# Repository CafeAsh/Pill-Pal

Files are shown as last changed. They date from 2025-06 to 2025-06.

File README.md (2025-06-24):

# Pill Pal Project
**Members:**  Ashton S, Damien W, Andrew J, Katherine S

## What is Pill Pal?

Pill Pal is a pill dispensing device developed by Team Fire through the course of UCLA's 2025 ECE 180DA/DW Capstone course.

Medication nonadherence poses serious risks, including hospitalization and mortality. Managing multiple medications demands strict adherence to schedules, accurate dosage measurement, and proper pill identification. In the United States alone, 43% of adults aged 65 and older take five or more prescription drugs.

Pill Pal simplifies medication management by offering an intuitive device for scheduling and dispensing pills. Unlike existing solutions like Hero Health and Meda Cube, Pill Pal stands out with advanced verification capabilities. It employs computer vision to not only count pills but also accurately identify them, reducing errors caused by both device and user.

## Scope of Project

* Aimed at individuals aged 65 and older, as well as their caregivers. 
* Accommodates pills ranging from 5mm to 21mm in size. 
* Compact design fits within maximum dimensions of 24in x 24in x 18in.
* Primary focus on pill verification subsystem.
* Outsourced pill retrieval method; no development efforts in this area.
* Targeting a verification error rate of less than 0.5%.

## Whats Involved
### Hardware
* Raspberry Pi 4B + 32GB Micro SD
* Raspberry Pi Camera Module V2
* Raspberry Pi 5" Touchscreen Display
* 2x MG90 Servos
* Difused White LED
### Computer Vision
* Ultralytics YoloV5n
* Custom Dataset
### User Interface
* Kivy Based Framework
### Housing
* Mixture of Standard and Matte PLA,

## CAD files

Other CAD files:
CAD_Files/Verification Blocks v20.f3z

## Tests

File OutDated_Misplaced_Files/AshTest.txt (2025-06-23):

Test: 1, Characteristics: {'oblong', 'pill', 'large', 'beige'}, Pill: ['MultiVitamin']
Test: 2, Characteristics: {'oblong', 'pill', 'large', 'beige'}, Pill: ['MultiVitamin']
Failed Test: 1, Characteristics: {'pill', 'oblong'}, Pill: []
Failed Test: 2, Characteristics: {'medium'}, Pill: []
Passed Test 1, Characteristics: {'oblong', 'beige'}, Pill: ['MultiVitamin']
Passed Test 2, Characteristics: {'oblong', 'beige'}, Pill: ['MultiVitamin']
Passed Test 3, Characteristics: {'oblong', 'beige'}, Pill: ['MultiVitamin']
Passed Test 4, Characteristics: {'oblong', 'beige'}, Pill: ['MultiVitamin']
Passed Test 5, Characteristics: {'oblong', 'beige'}, Pill: ['MultiVitamin']
Passed Test 6, Characteristics: {'oblong', 'beige'}, Pill: ['MultiVitamin']
Failed Test 1, Characteristics: {'oblong', 'pill'}, Pill: []
Failed Test 2, Characteristics: {'pill', 'large'}, Pill: []
Passed Test 3, Characteristics: {'oblong', 'white', 'small'}, Pill: ['Allertec']
Passed Test 4, Characteristics: {'medium', 'white'}, Pill: ['Zinc']
Failed Test 5, Characteristics: {'pill'}, Pill: []
Test Batch: 2025-05-14 21:56:29.531375Passed Test 1, Characteristics: {'medium', 'red', 'pill', 'blue'}, Pill: ['Tylenol']
Passed Test 2, Characteristics: {'large', 'oblong', 'beige'}, Pill: ['MultiVitamin']
Failed Test 3, Characteristics: {'pill'}, Pill: []
Test Batch: 2025-05-14 22:03:43.866070Test Batch: 2025-05-14 22:05:19.351595Failed Test 1, Characteristics: {'pill'}, Pill: []
Failed Test 2, Characteristics: {'pill', 'capsule', 'white'}, Pill: []
Failed Test 3, Characteristics: {'pill', 'white'}, Pill: []
Failed Test 4, Characteristics: {'capsule', 'pill'}, Pill: []
Failed Test 5, Characteristics: {'pill'}, Pill: []
Failed Test 6, Characteristics: {'pill'}, Pill: []

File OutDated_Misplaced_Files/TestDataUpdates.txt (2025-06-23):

Test: 1, Confidence: 0.8663991093635559
Test: 2, Confidence: 0.8826671838760376
Test: 3, Confidence: 0.8755373954772949
Test: 4, Confidence: 0.8511570692062378
Test: 5, Confidence: 0.8647085428237915
Test: 6, Confidence: 0.8529770970344543
Test: 7, Confidence: 0.8642621636390686
Test: 8, Confidence: 0.8169513940811157
Test: 9, Confidence: 0.8401616215705872
Test: 10, Confidence: 0.8167058825492859
Test: 11, Confidence: 0.753711462020874
Test: 12, Confidence: 0.8434830904006958
Test: 13, Confidence: 0.8218642473220825
Test: 14, Confidence: 0.8264126181602478
Test: 15, Confidence: 0.8553087115287781
Test: 16, Confidence: 0.7893893718719482
Test: 17, Confidence: 0.8077926635742188
Test: 18, Confidence: 0.8879213333129883
Test: 19, Confidence: 0.8521213531494141
Test: 20, Confidence: 0.8283798694610596
Test: 21, Confidence: 0.8602449297904968
Test: 22, Confidence: 0.64755779504776
Test: 23, Confidence: 0.8162557482719421
Test: 24, Confidence: 0.8518110513687134
Test: 25, Confidence: 0.8540529608726501
Test: 26, Confidence: 0.8430642485618591
Test: 27, Confidence: 0.8432045578956604
Test: 28, Confidence: 0.8785762190818787
Test: 29, Confidence: 0.8303031325340271
Test: 30, Confidence: 0.7792167067527771
Test: 31, Confidence: 0.8792150020599365
Test: 32, Confidence: 0.8754306435585022
Test: 33, Confidence: 0.8369922041893005
Test: 34, Confidence: 0.8724876642227173
Test: 35, Confidence: 0.7125908136367798
Test: 36, Confidence: 0.8801412582397461
Test: 37, Confidence: 0.8527312278747559
Test: 38, Confidence: 0.8252891898155212
Test: 39, Confidence: 0.8519672155380249
Test: 40, Confidence: 0.8726422786712646
Test: 41, Confidence: 0.6001267433166504
Test: 42, Confidence: 0.8835003972053528
Test: 43, Confidence: 0.8318778872489929
Test: 44, Confidence: 0.754368245601654
Test: 45, Confidence: 0.7924609780311584
Test: 46, Confidence: 0.8563061952590942
Test: 47, Confidence: 0.8038321733474731
Test: 48, Confidence: 0.8085771799087524
Test: 49, Confidence: 0.8533533215522766
Test: 50, Confidence: 0.8119551539421082
Test: 51, Confidence: 0.8488428592681885
Test: 52, Confidence: 0.8649629950523376
Test: 53, Confidence: 0.8574305772781372
Test: 54, Confidence: 0.8744310140609741
Test: 55, Confidence: 0.8364936709403992
Test: 56, Confidence: 0.8491111993789673
Test: 57, Confidence: 0.8860889673233032
Test: 58, Confidence: 0.824094831943512
Test: 59, Confidence: 0.8591299653053284
Test: 60, Confidence: 0.816805362701416
Test: 61, Confidence: 0.8369536995887756
Test: 62, Confidence: 0.8607133626937866
Test: 63, Confidence: 0.8628970384597778
Test: 64, Confidence: 0.7004595994949341
Test: 65, Confidence: 0.8639209866523743
Test: 66, Confidence: 0.83849036693573
Test: 67, Confidence: 0.8416141867637634
Test: 68, Confidence: 0.8494589328765869
Test: 69, Confidence: 0.8329309225082397
Test: 70, Confidence: 0.8591966032981873
Test: 71, Confidence: 0.8725012540817261
Test: 72, Confidence: 0.882864773273468
Test: 73, Confidence: 0.8827550411224365
Test: 74, Confidence: 0.8592625260353088
Test: 75, Confidence: 0.8543862104415894
Test: 76, Confidence: 0.8689223527908325
Test: 77, Confidence: 0.8844353556632996
Test: 78, Confidence: 0.8342261910438538
Test: 79, Confidence: 0.8248381018638611
Test: 80, Confidence: 0.8121533393859863
Test: 81, Confidence: 0.8526245355606079
Test: 82, Confidence: 0.8169139623641968
Test: 83, Confidence: 0.8201515674591064
Test: 84, Confidence: 0.8597942590713501
Test: 85, Confidence: 0.8630779385566711
Test: 86, Confidence: 0.8622211813926697
Test: 87, Confidence: 0.8374679684638977
Test: 88, Confidence: 0.8491995930671692
Test: 89, Confidence: 0.8860586881637573
Test: 90, Confidence: 0.8696560859680176
Test: 91, Confidence: 0.8290908336639404
Test: 92, Confidence: 0.8412095308303833
Test: 93, Confidence: 0.6310178637504578
Test: 94, Confidence: 0.880522608757019
Test: 95, Confidence: 0.8199472427368164
Test: 96, Confidence: 0.8109217286109924
Test: 97, Confidence: 0.8338972330093384
Test: 98, Confidence: 0.8236708641052246
Test: 99, Confidence: 0.6796160936355591
Test: 100, Confidence: 0.7799317836761475
Test: 9, Confidence: 0.8748241066932678
Test: 10, Confidence: 0.8788591027259827
Test: 11, Confidence: 0.8316600918769836
Test: 12, Confidence: 0.7983502149581909
Test: 13, Confidence: 0.815441906452179
Test: 14, Confidence: 0.7403838634490967
Test: 15, Confidence: 0.6905316114425659
Test: 16, Confidence: 0.8261948823928833
Test: 17, Confidence: 0.8175153732299805
Test: 18, Confidence: 0.8088531494140625
Test: 19, Confidence: 0.8539157509803772
Test: 20, Confidence: 0.7268420457839966
Test: 21, Confidence: 0.8576212525367737
Test: 22, Confidence: 0.8497840166091919
Test: 23, Confidence: 0.8285691142082214
Test: 24, Confidence: 0.874667763710022
Test: 25, Confidence: 0.8807705640792847
Test: 26, Confidence: 0.8769426941871643
Test: 27, Confidence: 0.8925943374633789
Test: 28, Confidence: 0.775532066822052
Test: 29, Confidence: 0.8142493367195129
Test: 30, Confidence: 0.7598199248313904
Test: 31, Confidence: 0.8821894526481628
Test: 32, Confidence: 0.7486389875411987
Test: 33, Confidence: 0.8874029517173767
Test: 34, Confidence: 0.8687301278114319
Test: 35, Confidence: 0.8379375338554382
Test: 36, Confidence: 0.8491209745407104
Test: 37, Confidence: 0.7861077189445496
Test: 38, Confidence: 0.8826022744178772
Test: 39, Confidence: 0.8248276114463806
Test: 40, Confidence: 0.8738111257553101
Test: 41, Confidence: 0.8320329785346985
Test: 42, Confidence: 0.6807191967964172
Test: 43, Confidence: 0.8621594309806824
Test: 44, Confidence: 0.8801345229148865
Test: 45, Confidence: 0.8657287955284119
Test: 46, Confidence: 0.6759946346282959
Test: 47, Confidence: 0.8897563219070435
Test: 48, Confidence: 0.8624711036682129
Test: 49, Confidence: 0.8487997055053711
Test: 50, Confidence: 0.5480730533599854
Test: 51, Confidence: 0.8382814526557922
Test: 52, Confidence: 0.8456729650497437
Test: 53, Confidence: 0.6184303164482117
Test: 54, Confidence: 0.8347060680389404
Test: 55, Confidence: 0.8688293099403381
Test: 1, Confidence: 0.8461774587631226
Test: 2, Confidence: 0.781511664390564
Test: 3, Confidence: 0.8389360308647156
Test: 4, Confidence: 0.8615061044692993
Test: 5, Confidence: 0.8335949182510376
Test: 6, Confidence: 0.7853469252586365
Test: 7, Confidence: 0.8862441778182983
Test: 8, Confidence: 0.7606112957000732
Test: 9, Confidence: 0.8670732975006104
Test: 10, Confidence: 0.8553711771965027
Test: 11, Confidence: 0.8486812114715576
Test: 12, Confidence: 0.8651771545410156
Test: 13, Confidence: 0.8754342794418335
Test: 14, Confidence: 0.8251563310623169
Test: 15, Confidence: 0.7951398491859436
Test: 16, Confidence: 0.8622942566871643
Test: 17, Confidence: 0.8205395340919495

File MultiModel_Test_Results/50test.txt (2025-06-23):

Test: 1, Characteristics: {'capsule', 'blue', 'red', 'medium'}, Pill: ['Tylenol']
Test: 2, Characteristics: {'capsule', 'red', 'medium', 'blue'}, Pill: ['Tylenol']
Test: 3, Characteristics: {'capsule', 'red', 'medium', 'blue'}, Pill: ['Tylenol']
Test: 4, Characteristics: {'capsule', 'blue', 'red', 'medium'}, Pill: ['Tylenol']
Test: 5, Characteristics: {'capsule', 'red', 'medium', 'blue'}, Pill: ['Tylenol']
Test: 1, Characteristics: {'blue', 'red', 'capsule', 'medium'}, Pill: ['Tylenol']
Test: 2, Characteristics: {'blue', 'red', 'capsule', 'medium'}, Pill: ['Tylenol']
Test: 3, Characteristics: {'blue', 'red', 'capsule'}, Pill: ['Tylenol']
Test: 4, Characteristics: {'blue', 'red', 'capsule', 'medium'}, Pill: ['Tylenol']
Test: 5, Characteristics: {'blue', 'red', 'medium'}, Pill: ['Tylenol']
Test: 6, Characteristics: {'blue', 'red', 'capsule', 'medium'}, Pill: ['Tylenol']
Test: 7, Characteristics: {'blue', 'red'}, Pill: ['Tylenol']
Test: 8, Characteristics: {'blue', 'red', 'capsule'}, Pill: ['Tylenol']
Test: 9, Characteristics: {'blue', 'red', 'capsule', 'medium'}, Pill: ['Tylenol']
Test: 10, Characteristics: {'blue', 'red', 'capsule', 'medium'}, Pill: ['Tylenol']
Test: 11, Characteristics: {'blue', 'red', 'capsule', 'medium'}, Pill: ['Tylenol']
Test: 12, Characteristics: {'blue', 'red', 'capsule', 'medium'}, Pill: ['Tylenol']
Test: 13, Characteristics: {'blue', 'red', 'capsule', 'medium'}, Pill: ['Tylenol']
Test: 14, Characteristics: {'blue', 'red', 'capsule', 'medium'}, Pill: ['Tylenol']
Test: 15, Characteristics: {'blue', 'red', 'capsule', 'medium'}, Pill: ['Tylenol']
Test: 16, Characteristics: {'blue', 'red', 'capsule', 'medium'}, Pill: ['Tylenol']
Test: 17, Characteristics: {'blue', 'red', 'capsule'}, Pill: ['Tylenol']

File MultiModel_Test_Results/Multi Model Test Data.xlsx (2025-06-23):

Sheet: Aleve
Test # | Fail/Pass | Color | Shape | Size | Pill
1 | Pass | Blue | Oblong | Medium | Aleve
2 | Fail | NA | NA | NA | NA
3 | Pass | Blue | Oblong | Medium | Aleve
4 | Fail | NA | NA | Medium | NA
5 | Pass | Blue | Oblong | Medium | Aleve
6 | Fail | NA | NA | Medium | NA
7 | Pass | Blue | Oblong | Medium | Aleve
8 | Pass | Blue | Oblong | Medium | Aleve
9 | Fail | NA | NA | Medium | NA
10 | Fail | NA | NA | Medium | NA
11 | Pass | Blue | NA | Medium | Aleve
12 | Pass | Blue | Oblong | NA | Aleve
13 | Fail | NA | NA | NA | NA
14 | Fail | NA | Oblong | Medium | NA
15 | Fail | NA | Oblong | Medium | NA
16 | Pass | Blue | Oblong | NA | Aleve
17 | Fail | NA | NA | NA | NA
18 | Pass | Blue | NA | Medium | Aleve
19 | Pass | Blue | Oblong | Medium | Aleve
20 | Fail | Blue | NA | Medium | NA
21 | Pass | Blue | Oblong | Medium | Aleve
22 | Pass | Blue | Oblong | NA | Aleve
23 | Fail | Blue | NA | NA | NA
24 | Fail | Blue | NA | Medium | NA
25 | Fail | Blue | NA | NA | NA
26 | Pass | Blue | NA | Medium | Aleve
27 | Pass | Blue | NA | Medium | Aleve
28 | Pass | Blue | Oblong | NA | Aleve
29 | Fail | NA | NA | NA | NA
30 | Pass | Blue | NA | Medium | Aleve
31 | Pass | Blue | Oblong | NA | Aleve
32 | Fail | NA | NA | Medium | NA
33 | Pass | Blue | Oblong | NA | Aleve
34 | Pass | Blue | Oblong | Medium | Aleve
35 | Fail | Blue | NA | NA | NA
36 | Pass | Blue | NA | Medium | Aleve
37 | Pass | Blue | NA | Medium | Aleve
38 | Fail | NA | NA | NA | NA
39 | Fail | NA | NA | Medium | NA
40 | Pass | Blue | Oblong | Medium | Aleve
41 | Pass | Blue | Oblong | NA | Aleve
42 | Pass | Blue | Oblong | Medium | Aleve
43 | Fail | Blue | NA | NA | NA
44 | Pass | Blue | Oblong | Medium | Aleve
45 | Pass | Blue | NA | Medium | Aleve
46 | Fail | Blue | NA | NA | NA
47 | Fail | Blue | Oblong | Medium | NA
48 | Fail | Blue | Oblong | NA | NA
49 | Fail | Blue | NA | Medium | NA
50 | Pass | Blue | Oblong | Medium | Aleve
51 | Pass | Blue | NA | Medium | Aleve

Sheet: Allertec
Test # | Fail/Pass | Color | Shape | Size | Pill
1 | Pass | White | Oblong | Small | Allertec
2 | Fail | NA | Oblong | Small | NA
3 | Fail | White | Oblong | NA | NA
4 | Fail | NA | Oblong | Small | NA
5 | Pass | White | Oblong | Small | Allertec
6 | Fail | NA | NA | NA | NA
7 | Fail | White | Oblong | Small | Allertec
8 | Fail | NA | Oblong | NA | NA
9 | Pass | White | Oblong | Small | Allertec
10 | Fail | White | Oblong | NA | NA
11 | Fail | NA | NA | NA | NA
12 | Fail | White | Oblong | NA | NA
13 | Fail | NA | Oblong | NA | NA
14 | Pass | Red | Disk | NA | Iron
15 | Pass | Red | NA | NA | Iron
16 | Pass | White | Oblong | Small | Allertec
17 | Fail | NA | Oblong | NA | NA
18 | Pass | White | Oblong | Small | Allertec
19 | Pass | White | Oblong | Small | Allertec
20 | Fail | NA | NA | NA | NA
21 | Pass | White | Oblong | Small | Allertec
22 | Fail | NA | Oblong | Small | NA
23 | Fail | NA | Oblong | NA | NA
24 | Pass | White | Oblong | Small | Allertec
25 | Fail | NA | Oblong | Small | NA
26 | Fail | NA | NA | NA | NA
27 | Pass | White | Oblong | Small | Allertec
28 | Fail | NA | Oblong | NA | NA
29 | Fail | NA | Oblong | NA | NA
30 | Pass | NA | NA | Medium | NA
31 | Pass | White | Oblong | Small | Allertec
32 | Fail | NA | Oblong | NA | NA
33 | Fail | NA | NA | NA | NA
34 | Fail | NA | NA | NA | NA
35 | Fail | NA | NA | NA | NA
36 | Pass | Red | Disk | NA | Iron
37 | Fail | White | Oblong | NA | NA
38 | Pass | White | Oblong | Small | Allertec
39 | Fail | NA | Oblong | NA | NA
40 | Fail | NA | NA | NA | NA
41 | Fail | NA | Oblong | NA | NA
42 | Fail | NA | NA | NA | NA
43 | Pass | White | Oblong | Small | Allertec
44 | Fail | White | Oblong | NA | NA
45 | Fail | NA | NA | NA | NA
46 | Fail | NA | Oblong | NA | NA
47 | Pass | White | Oblong | Small | Allertec
48 | Fail | White | Oblong | NA | NA
49 | Fail | NA | NA | NA | NA
50 | Fail | NA | NA | NA | NA
51 | Fail | NA | Oblong | NA | NA
52 | Fail | NA | NA | NA | NA
53 | Fail | NA | NA | NA | NA
54 | Fail | NA | NA | NA | NA

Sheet: Caffeine
Test # | Fail/Pass | Color | Shape | Size | Pill
1 | Fail | NA | Capsule | NA | NA
2 | Fail | NA | Capsule | NA | NA
3 | Fail | NA | NA | NA | NA
4 | Fail | NA | Capsule | NA | NA
5 | Fail | NA | NA | NA | NA
6 | Fail | NA | NA | NA | NA
7 | Fail | White | Capsule | NA | NA
8 | Fail | White | Capsule | NA | NA
9 | Fail | White | NA | NA | NA
10 | Fail | NA | Capsule | NA | NA
11 | Pass | White | Capsule | NA | Caffeine
12 | Fail | NA | NA | NA | NA
13 | Fail | NA | Capsule | NA | NA
14 | Fail | White | NA | NA | NA
15 | Fail | White | NA | NA | NA
16 | Fail | White | Capsule | NA | NA
17 | Fail | White | Capsule | NA | NA
18 | Fail | White | Capsule | NA | NA
19 | Fail | White | NA | NA | NA
20 | Fail | NA | NA | NA | NA
21 | Fail | White | NA | NA | NA
22 | Fail | NA | NA | NA | NA
23 | Fail | NA | Capsule | NA | NA
24 | Fail | NA | Capsule | NA | NA
25 | Fail | NA | Capsule | NA | NA
26 | Fail | White | NA | NA | NA
27 | Fail | White | NA | NA | NA
28 | Fail | NA | Capsule | NA | NA
29 | Fail | White | Capsule | NA | NA
30 | Fail | White | NA | NA | NA
31 | Fail | NA | Capsule | NA | NA
32 | Fail | White | NA | NA | NA
33 | Fail | NA | NA | NA | NA
34 | Fail | NA | Capsule | NA | NA
35 | Fail | NA | Capsule | NA | NA
36 | Fail | White | Capsule | NA | NA
37 | Fail | White | NA | NA | NA
38 | Fail | White | NA | NA | NA
39 | Fail | NA | Capsule | NA | NA
40 | Fail | White | NA | NA | NA
41 | Fail | White | NA | NA | NA
42 | Fail | NA | Capsule | NA | NA
43 | Fail | NA | Capsule | NA | NA
44 | Fail | NA | Capsule | NA | NA
45 | Fail | NA | NA | NA | NA
46 | Fail | NA | Capsule | NA | NA
47 | Fail | NA | NA | NA | NA
48 | Fail | NA | Capsule | NA | NA
49 | Fail | NA | Capsule | NA | NA
50 | Fail | White | Capsule | NA | NA

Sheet: Cordyceps
Test # | Fail/Pass | Color | Shape | Size | Pill
1 | Fail | NA | NA | Large | NA
2 | Fail | NA | NA | Large | NA
3 | Fail | NA | NA | Large | NA
4 | Fail | NA | NA | Large | NA
5 | Fail | NA | NA | Large | NA
6 | Fail | NA | NA | Large | NA
7 | Fail | NA | NA | Large | NA
8 | Fail | NA | NA | Large | NA
9 | Fail | NA | NA | Large | NA
10 | Fail | NA | NA | Large | NA
11 | Fail | NA | NA | Large | NA
12 | Fail | NA | NA | Large | NA
13 | Fail | NA | NA | Large | NA
14 | Fail | NA | NA | Large | NA
15 | Fail | NA | NA | Large | NA
16 | Fail | NA | NA | Large | NA
17 | Fail | NA | NA | Large | NA
18 | Fail | NA | NA | Large | NA
19 | Fail | NA | NA | Large | NA
20 | Fail | NA | NA | Large | NA
21 | Fail | NA | NA | Large | NA
22 | Fail | NA | NA | Large | NA
23 | Fail | NA | NA | Large | NA
24 | Fail | NA | NA | Large | NA
25 | Fail | NA | NA | Large | NA
26 | Fail | NA | NA | Large | NA
27 | Fail | NA | NA | Large | NA
28 | Fail | NA | NA | Large | NA
29 | Fail | NA | Capsule | Large | NA
30 | Fail | NA | NA | Large | NA
31 | Fail | NA | NA | Large | NA
32 | Fail | NA | NA | Large | NA
33 | Fail | NA | NA | Large | NA
34 | Fail | NA | NA | Large | NA
35 | Fail | NA | Capsule | Large | NA
36 | Fail | NA | NA | Large | NA
37 | Fail | Beige | NA | NA | NA
38 | Fail | NA | NA | Large | NA
39 | Fail | NA | NA | Large | NA
40 | Fail | NA | Capsule | Large | NA
41 | Fail | NA | NA | Large | NA
42 | Fail | Beige | NA | Large | NA
43 | Fail | NA | NA | Large | NA
44 | Fail | NA | NA | Large | NA
45 | Fail | NA | NA | Large | NA
46 | Fail | NA | NA | Large | NA
47 | Fail | NA | NA | Large | NA
48 | Fail | NA | NA | Large | NA
49 | Fail | NA | NA | Large | NA
50 | Fail | NA | Capsule | Large | NA

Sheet: Iron
Test # | Pass/Fail | Color | Shape | Size | Pill
1 | Pass | Red | Disk | Medium | Iron
2 | Pass | Red | Disk | Medium | Iron
3 | Fail | Red | NA | Medium | NA
4 | Pass | Red | Disk | Medium | Iron
5 | Fail | NA | NA | Medium | NA
6 | Pass | Red | Disk | Medium | Iron
7 | Pass | Red | Disk | Medium | Iron
8 | Fail | NA | Disk | Medium | NA
9 | Pass | Red | Disk | Medium | Iron
10 | Pass | Red | Disk | Medium | Iron
11 | Pass | Red | Disk | Medium | Iron
12 | Pass | Red | Disk | Medium | Iron
13 | Pass | Red | Disk | Medium | Iron
14 | Fail | NA | NA | Medium | NA
15 | Pass | Red | Disk | Medium | Iron
16 | Pass | Red | Disk | Medium | Iron
17 | Pass | Red | Disk | Medium | Iron
18 | Pass | Red | Disk | Medium | Iron
19 | Pass | Red | Disk | Medium | Iron
20 | Fail | NA | NA | Medium | NA
21 | Fail | NA | Disk | Medium | NA
22 | Pass | Red | Disk | Medium | Iron
23 | Fail | NA | Disk | Medium | NA
24 | Fail | Red | NA | Medium | NA
25 | Fail | NA | NA | Medium | NA
26 | Pass | Red | Disk | Medium | Iron
27 | Fail | Red | NA | Medium | NA
28 | Fail | NA | NA | Medium | NA
29 | Fail | Red | NA | Medium | NA
30 | Pass | Red | Disk | Medium | Iron
31 | Pass | Red | Disk | Medium | Iron
32 | Fail | Red | NA | Medium | NA
35 | Fail | Red | NA | Medium | NA
36 | Fail | NA | Disk | Medium | NA
37 | Fail | NA | NA | Medium | NA
38 | Pass | Red | Disk | Medium | Iron
39 | Pass | Red | Disk | Medium | Iron
40 | Pass | Red | Disk | Medium | Iron
41 | Pass | Red | Disk | Medium | Iron
42 | Pass | Red | Disk | Medium | Iron
43 | Pass | Red | Disk | Medium | Iron
44 | Pass | Red | Disk | Medium | Iron
45 | Fail | NA | NA | Medium | NA
46 | Pass | Red | Disk | Medium | Iron
47 | Fail | NA | NA | Medium | NA
48 | Pass | Red | Disk | Medium | Iron
49 | Fail | Red | NA | Medium | NA
50 | Fail | NA | NA | Medium | NA
51 | Fail | Red | NA | Medium | NA
52 | Pass | Red | Disk | Medium | Iron
53 | Pass | Red | Disk | Medium | Iron
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

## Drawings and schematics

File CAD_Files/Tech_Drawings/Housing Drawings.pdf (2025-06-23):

# 2.98in 4.52in

# 2.05in 1.94in Ø12.13in 2.3in

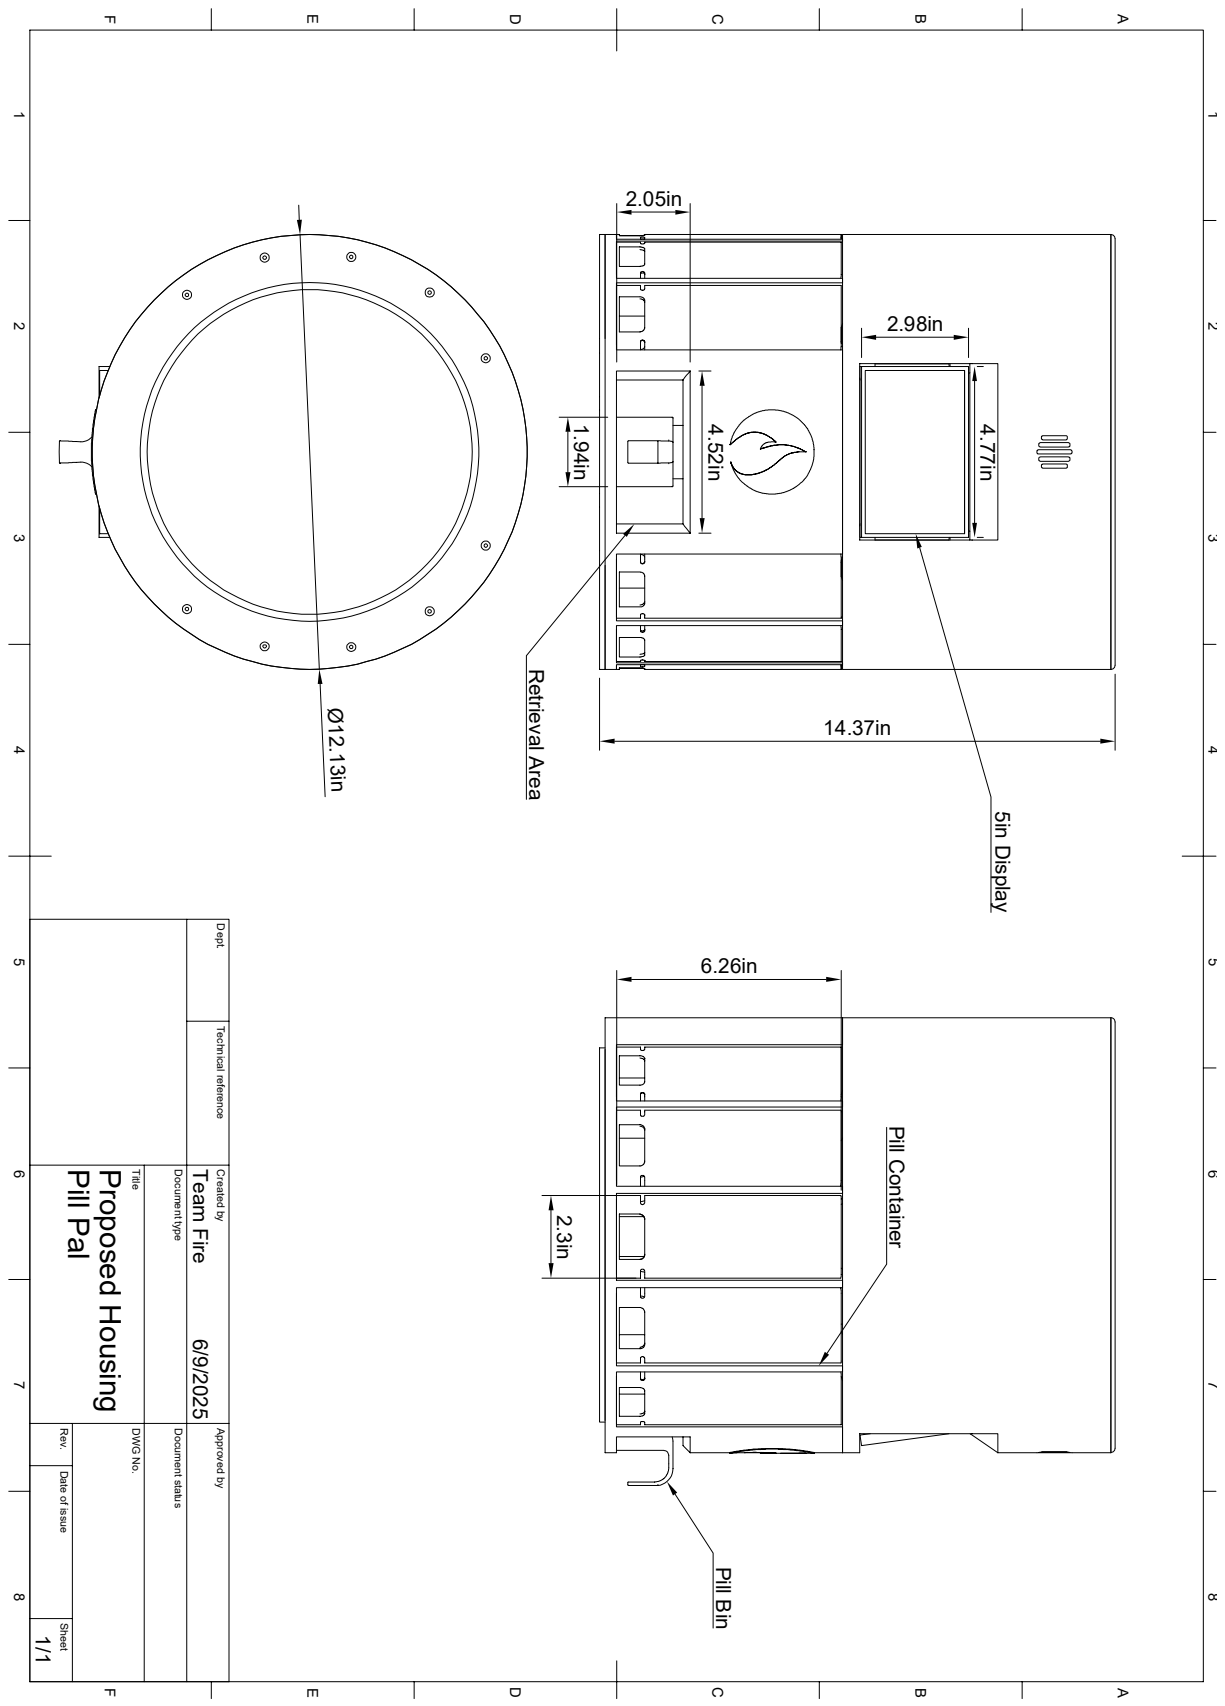
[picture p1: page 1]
5in Display Pill Container Pill Bin Retrieval Area

1 A 2 3 4 5 6 7 8 1 2 3 4 5 6 7 8 FEDCB FEDCBA Dept. Technical reference Created by Approved by Title DWG No. Document type Document status Rev. Date of issue Sheet 6/9/2025 1/1 Pill Pal Proposed Housing Team Fire

4.37in 2.36in 3.37in | .7in | 31 ° 5

.08in

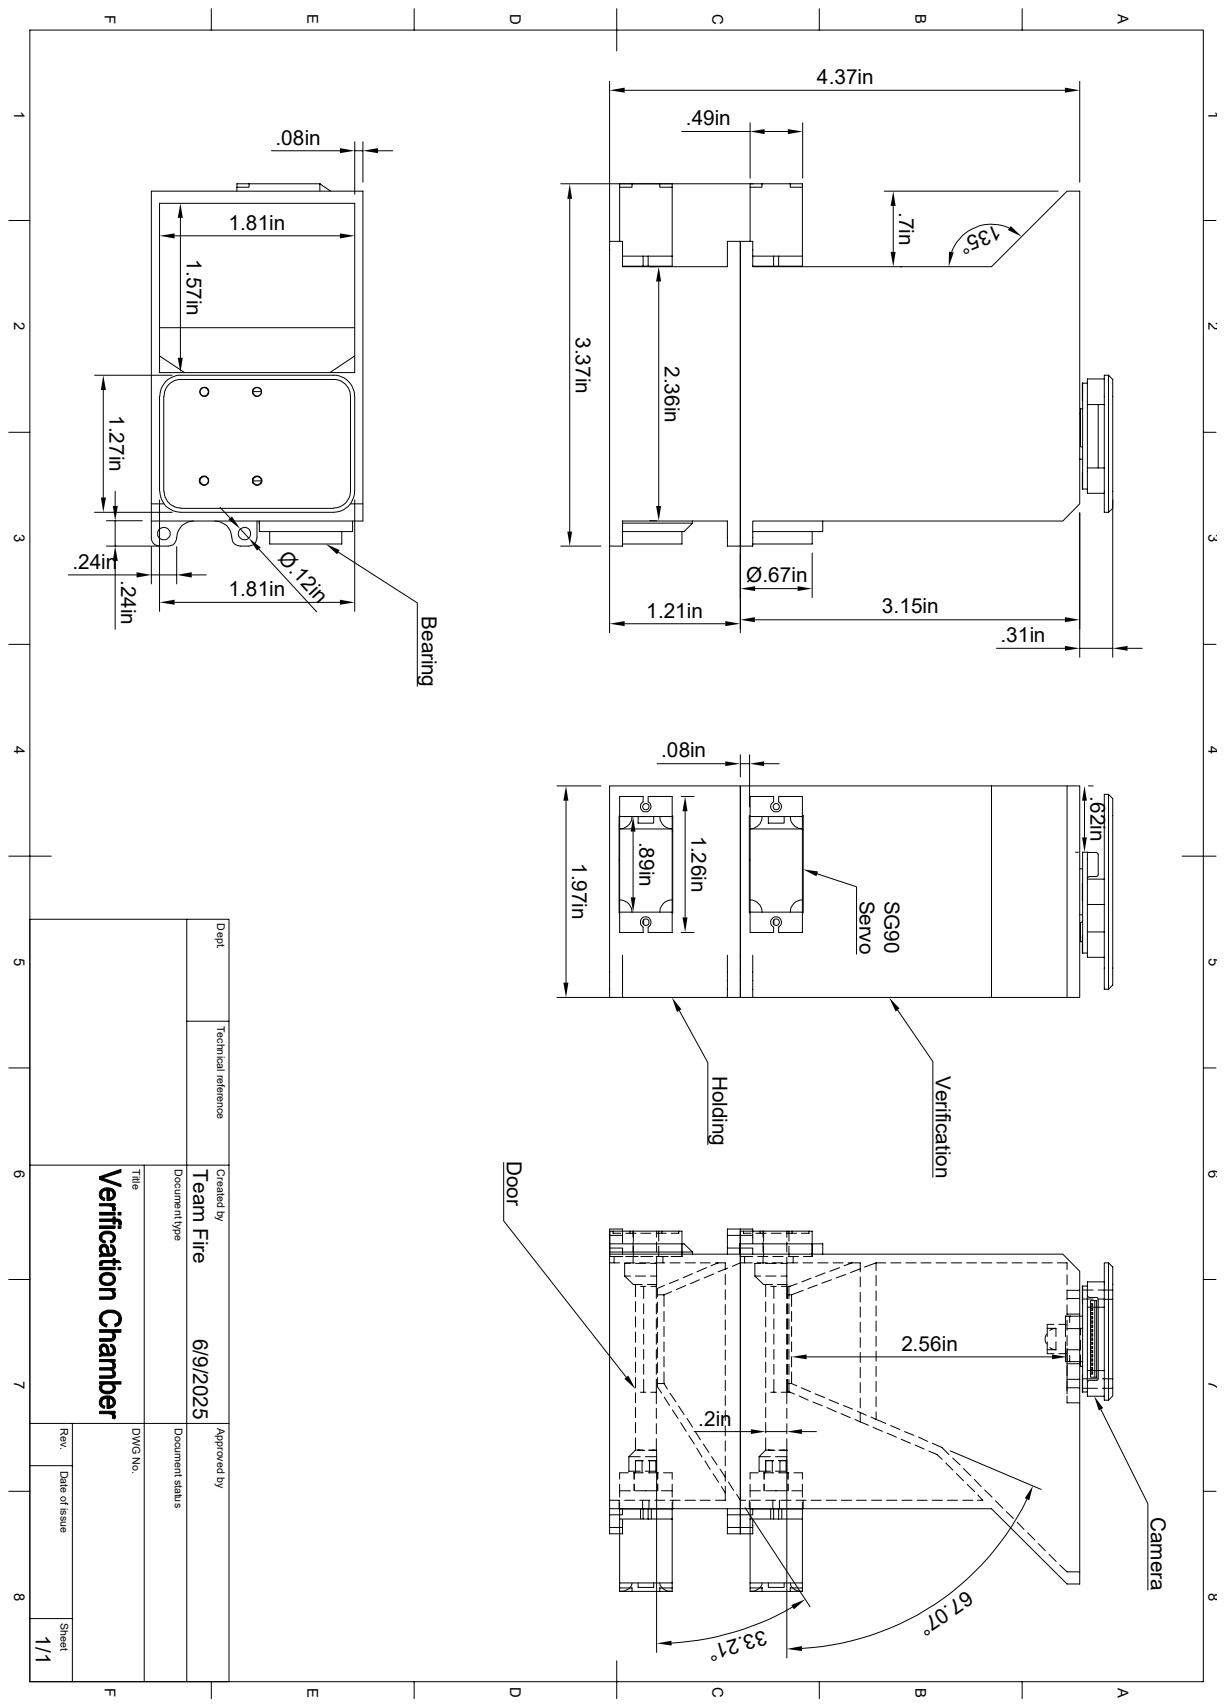
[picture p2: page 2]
2.56in 33 12. ° Holding; Verification; Camera Servo SG90 Bearing; Door

1 A 2 3 4 5 6 7 8 1 2 3 4 5 6 7 8 FEDCB FEDCBA Dept. Technical reference Created by Approved by Title DWG No. Document type Document status Rev. Date of issue Sheet 6/9/2025 1/1 Team Fire

6.26in

# .71in 1.27in

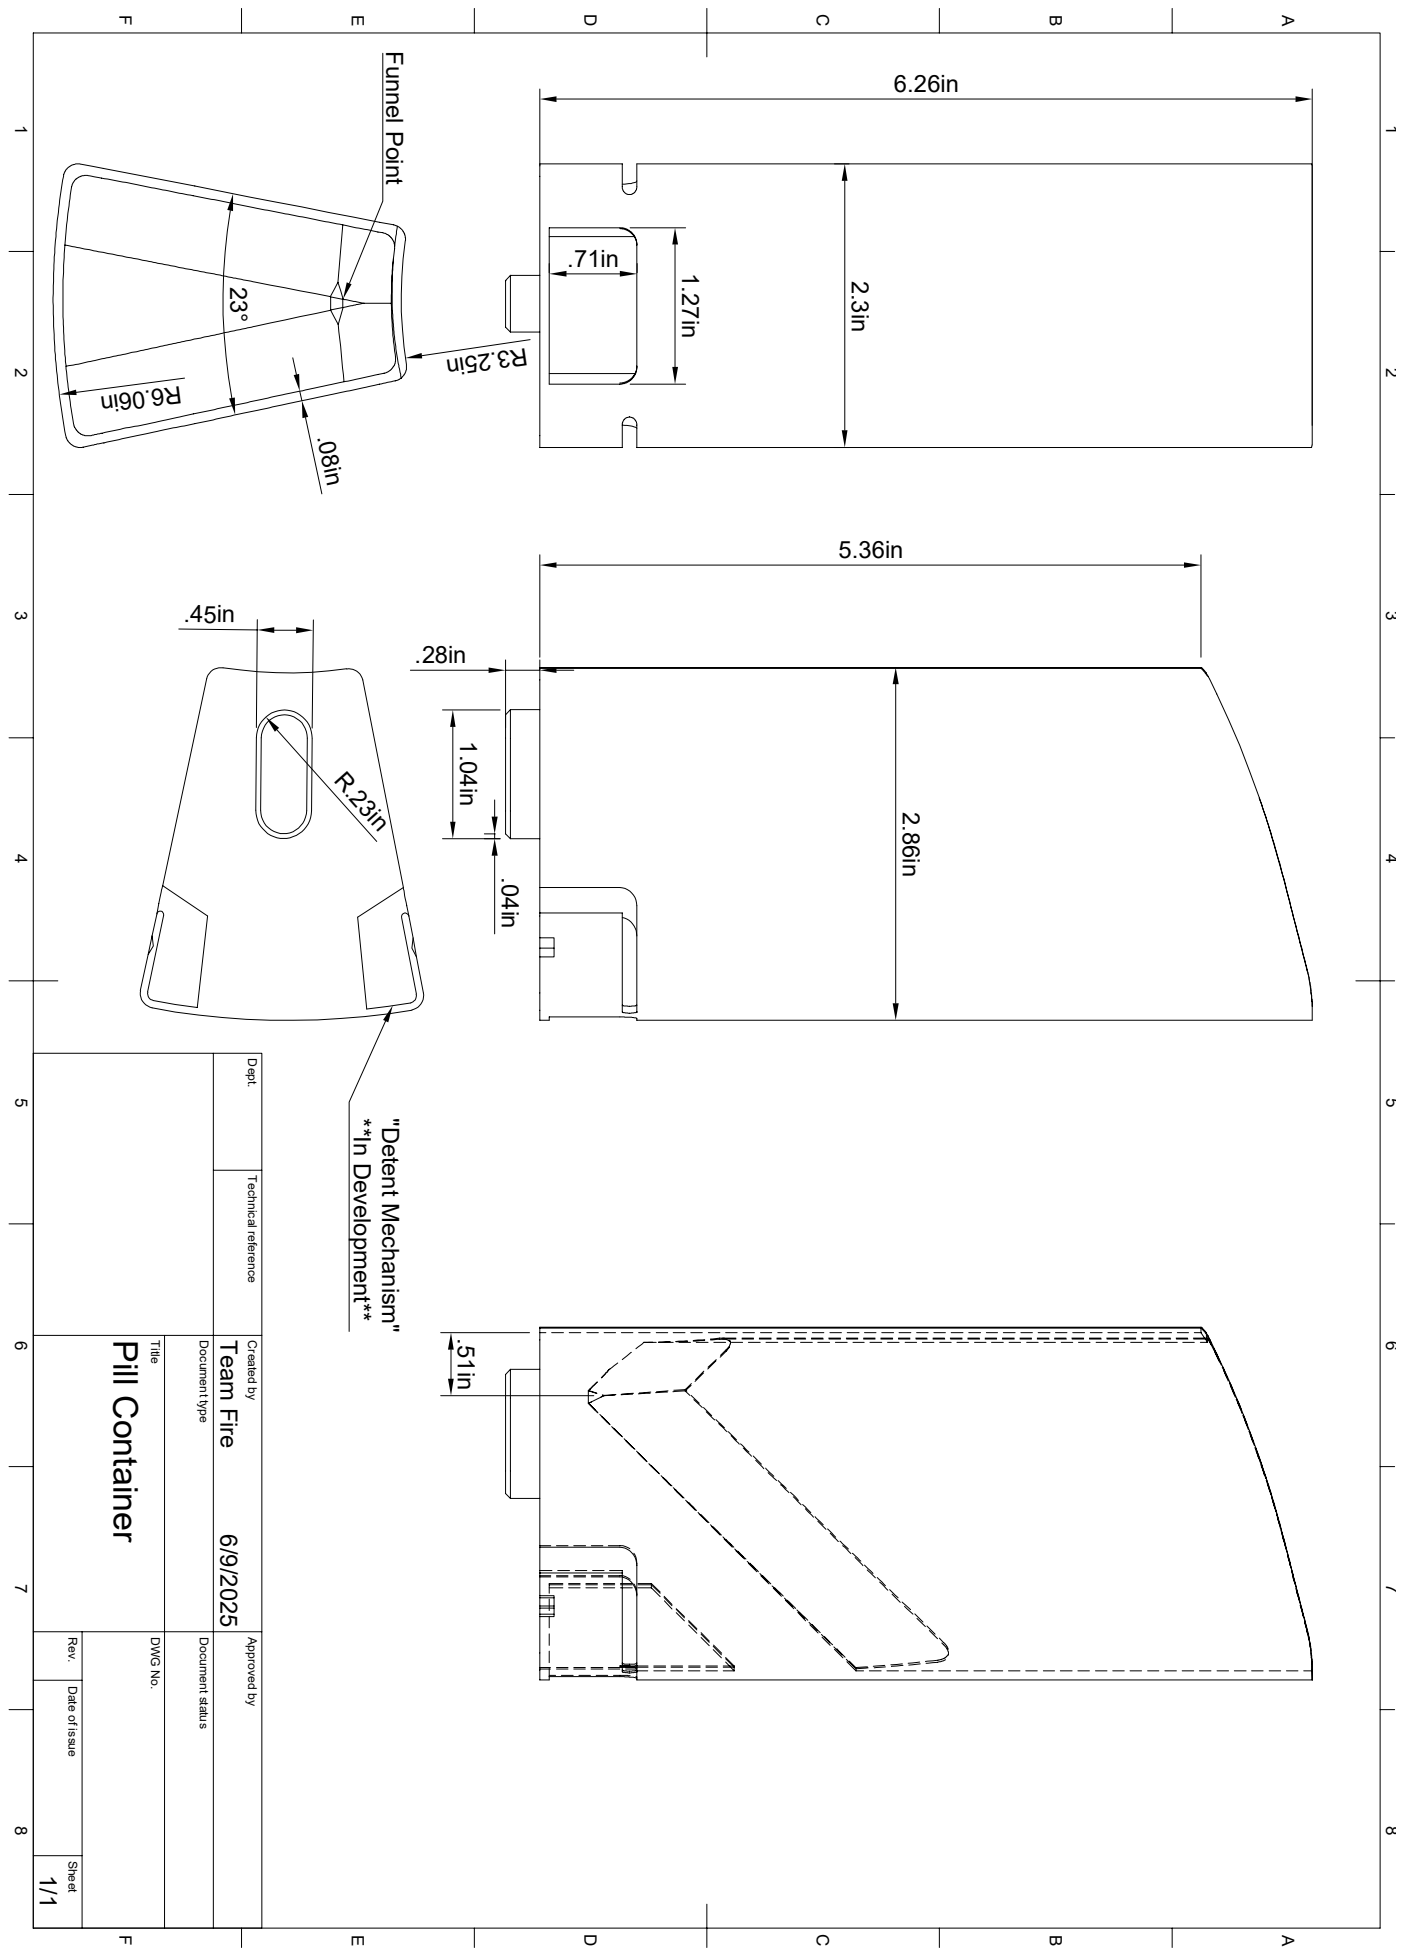
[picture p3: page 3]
2.86in Funnel Point **In Development** "Detent Mechanism"

1 A 2 3 4 5 6 7 8 1 2 3 4 5 6 7 8 FEDCB FEDCBA Dept. Technical reference Created by Approved by Title DWG No. Document type Document status Rev. Date of issue Sheet 6/9/2025 1/1 Pill Container Team Fire 52. 3 R ni i 60. 6 R n 23° 2.3in

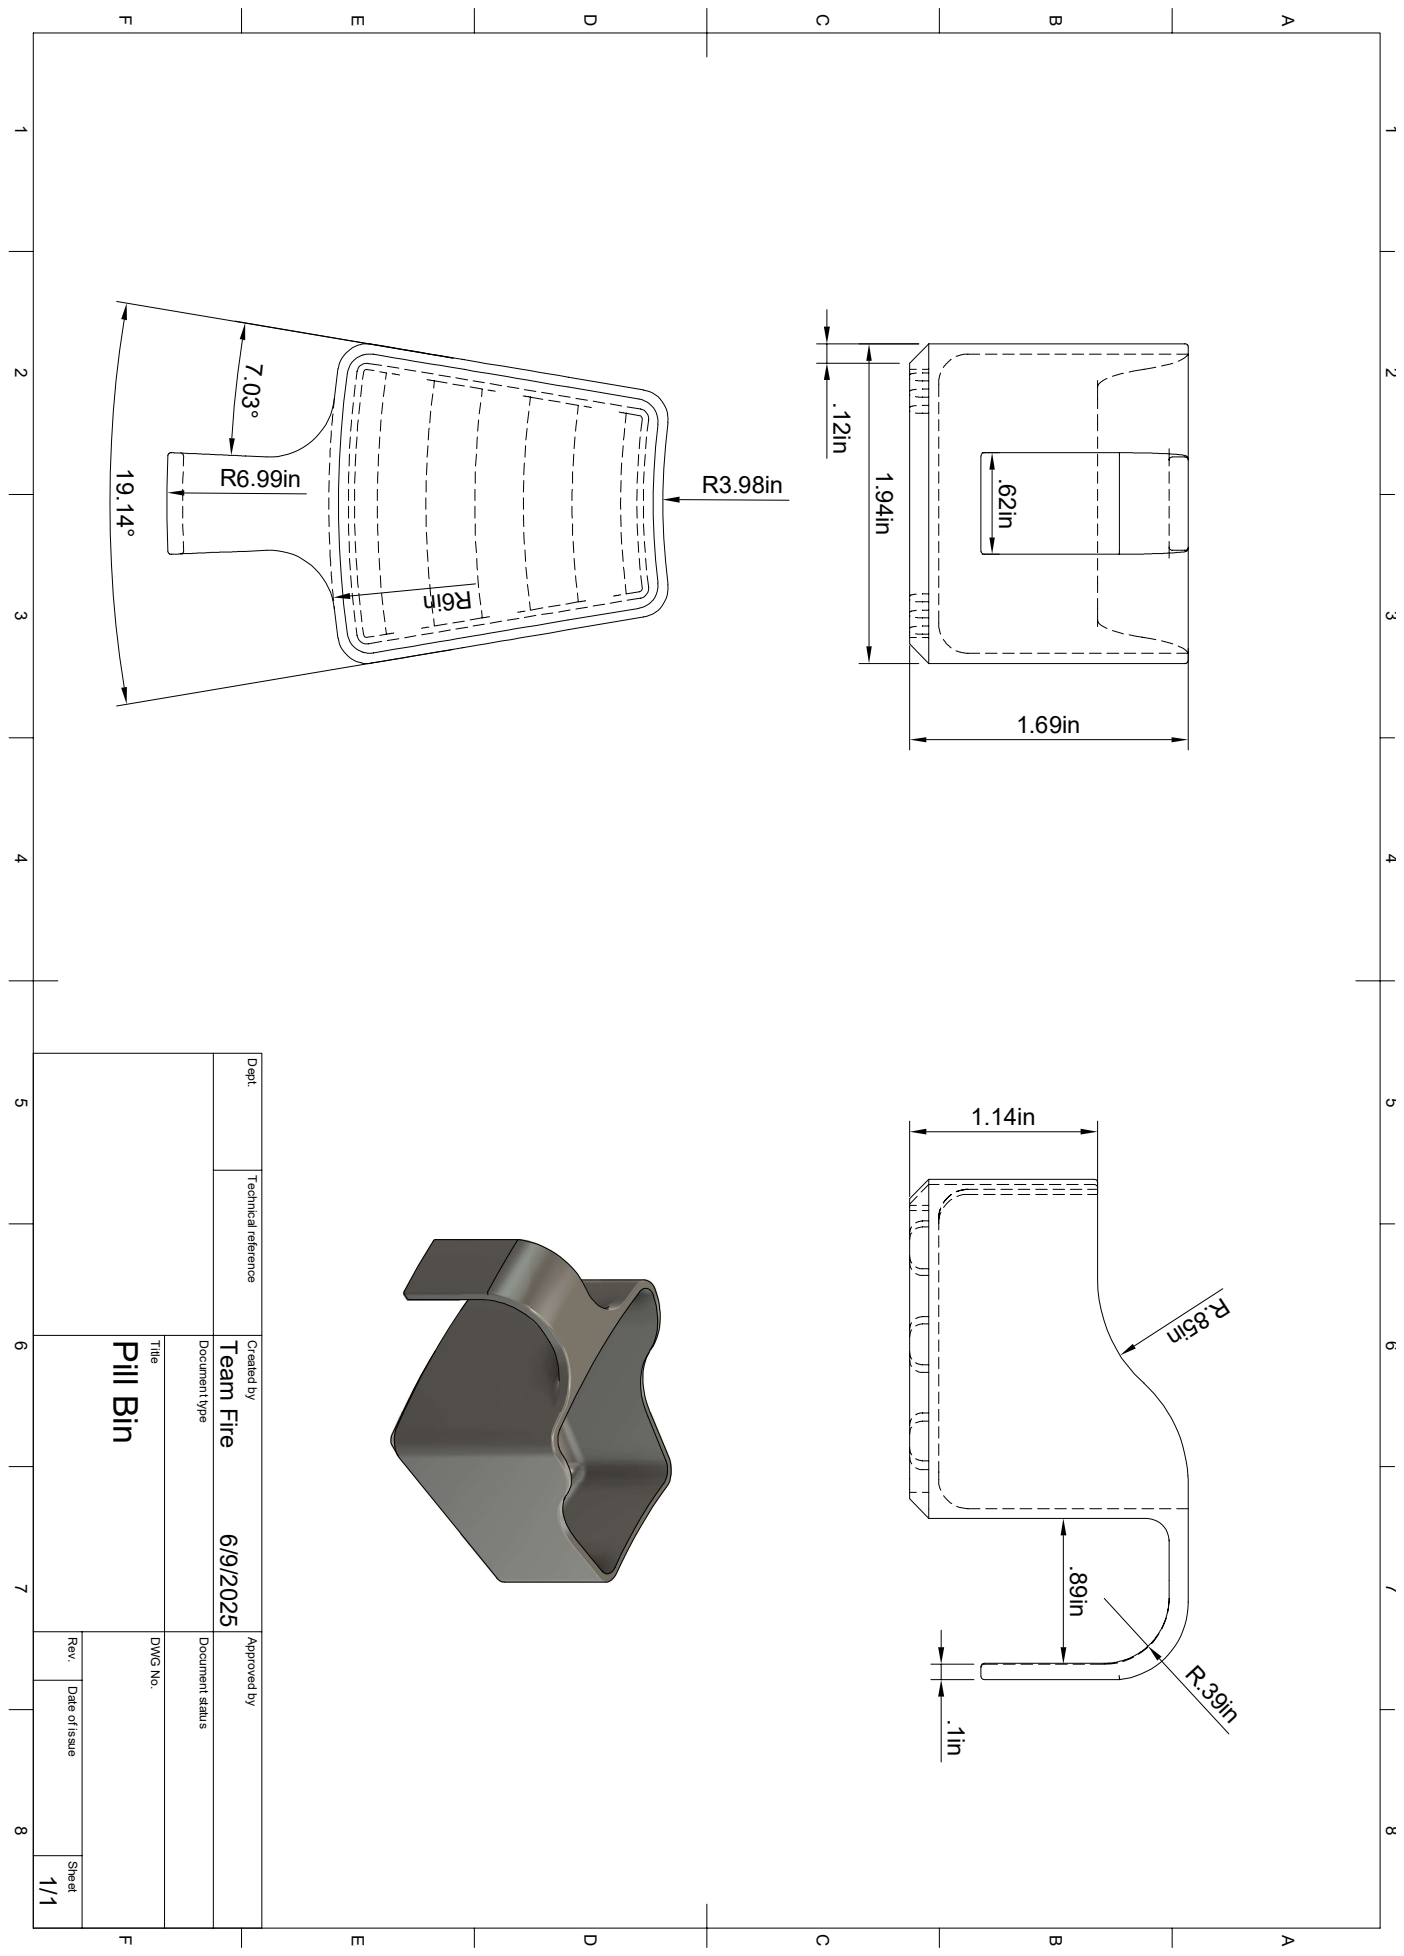
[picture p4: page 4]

1 A 2 3 4 5 6 7 8 1 2 3 4 5 6 7 8 FEDCB FEDCBA Dept. Technical reference Created by Approved by Title DWG No. Document type Document status Rev. Date of issue Sheet 6/9/2025 1/1 Pill Bin Team Fire R3.98in ni 6 R 19.14° R6.99in 7 0. 3°1.94in .62in .12in

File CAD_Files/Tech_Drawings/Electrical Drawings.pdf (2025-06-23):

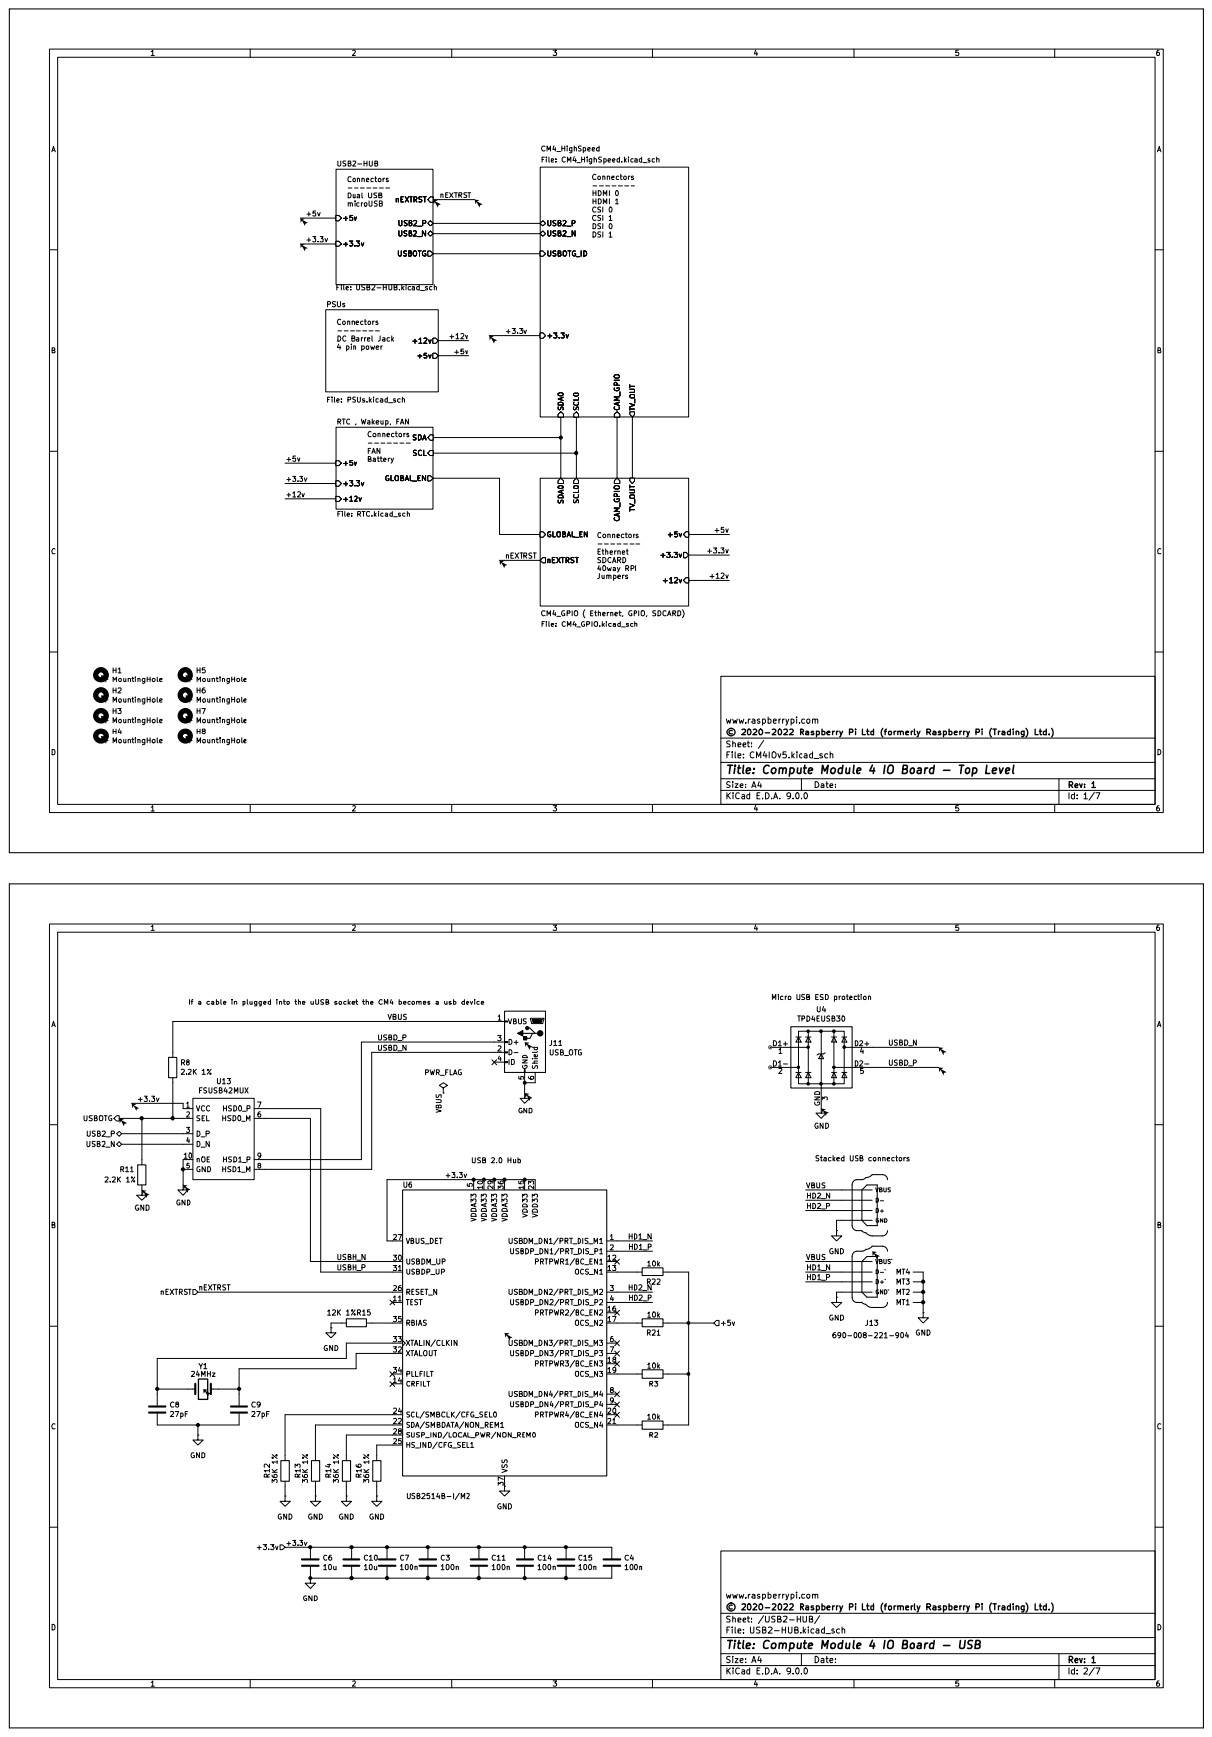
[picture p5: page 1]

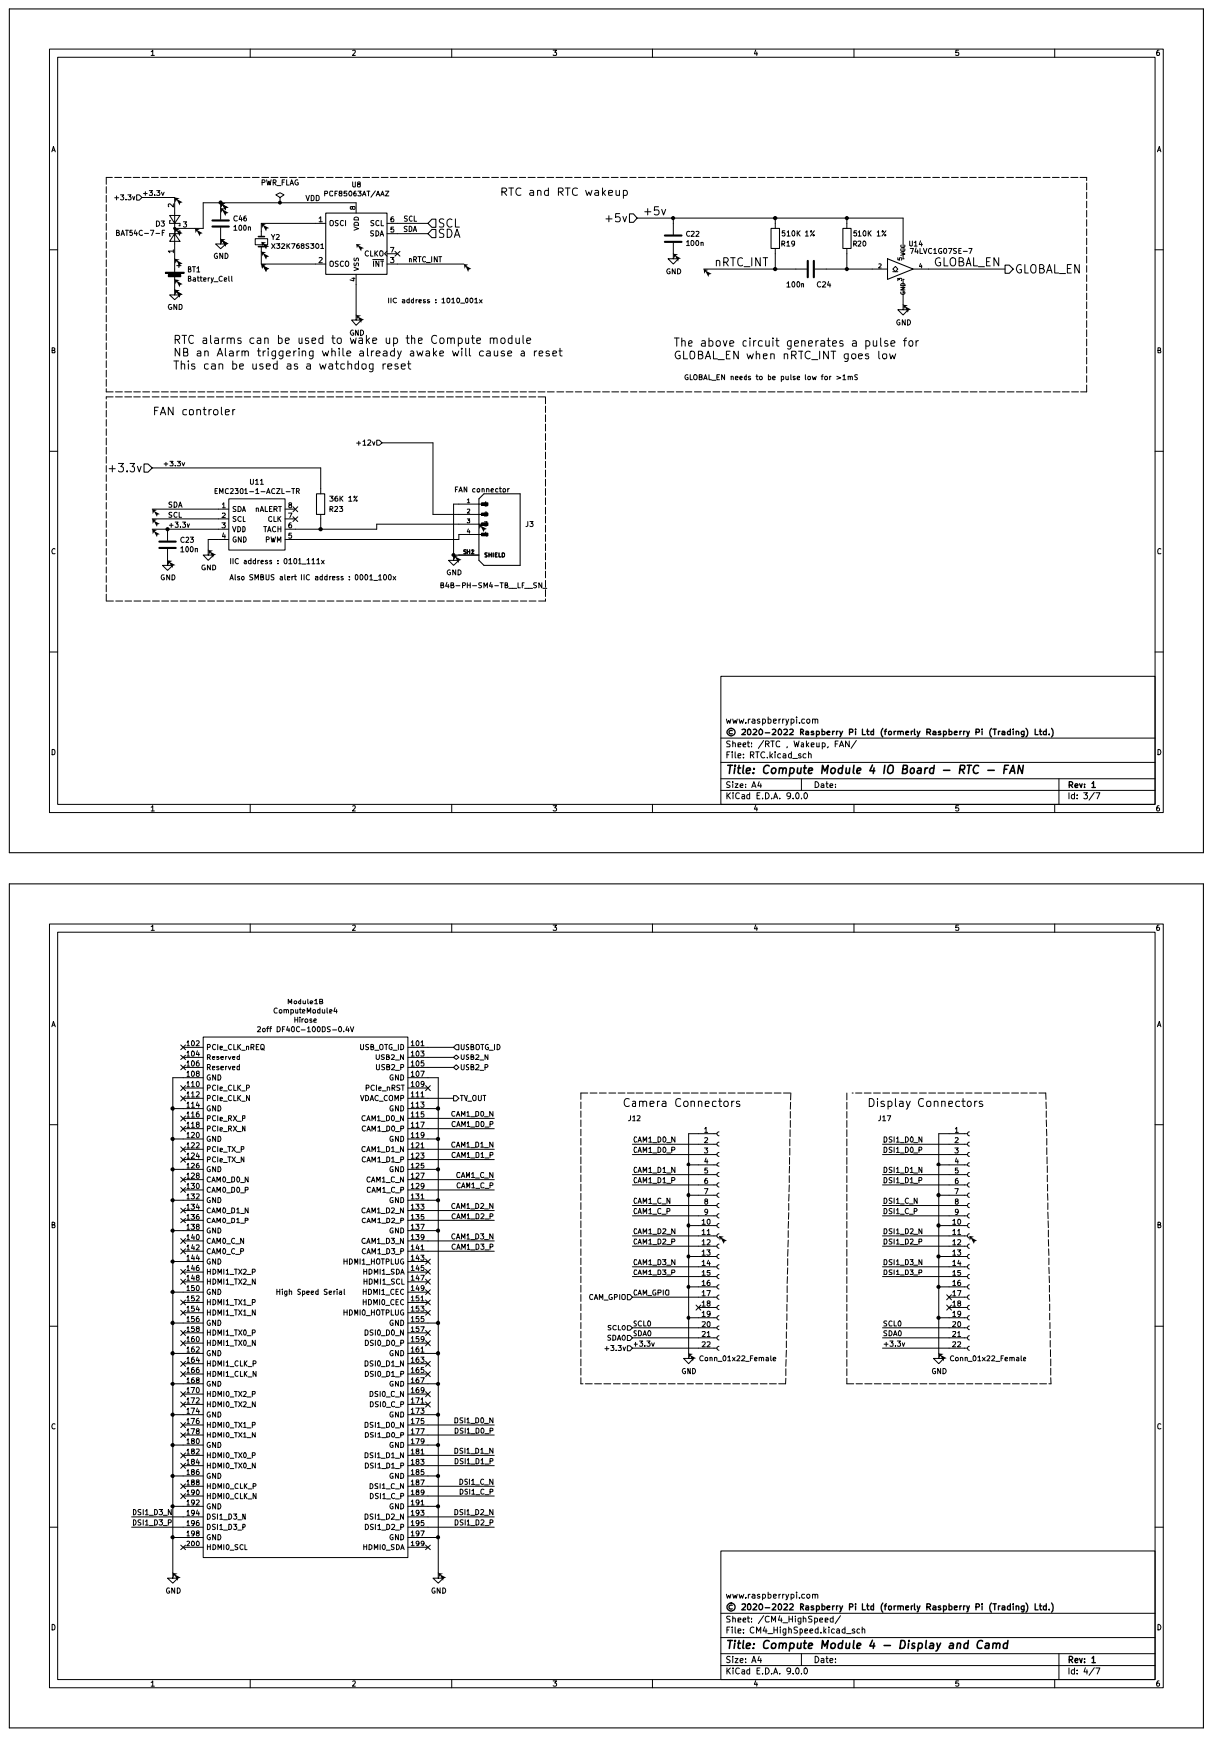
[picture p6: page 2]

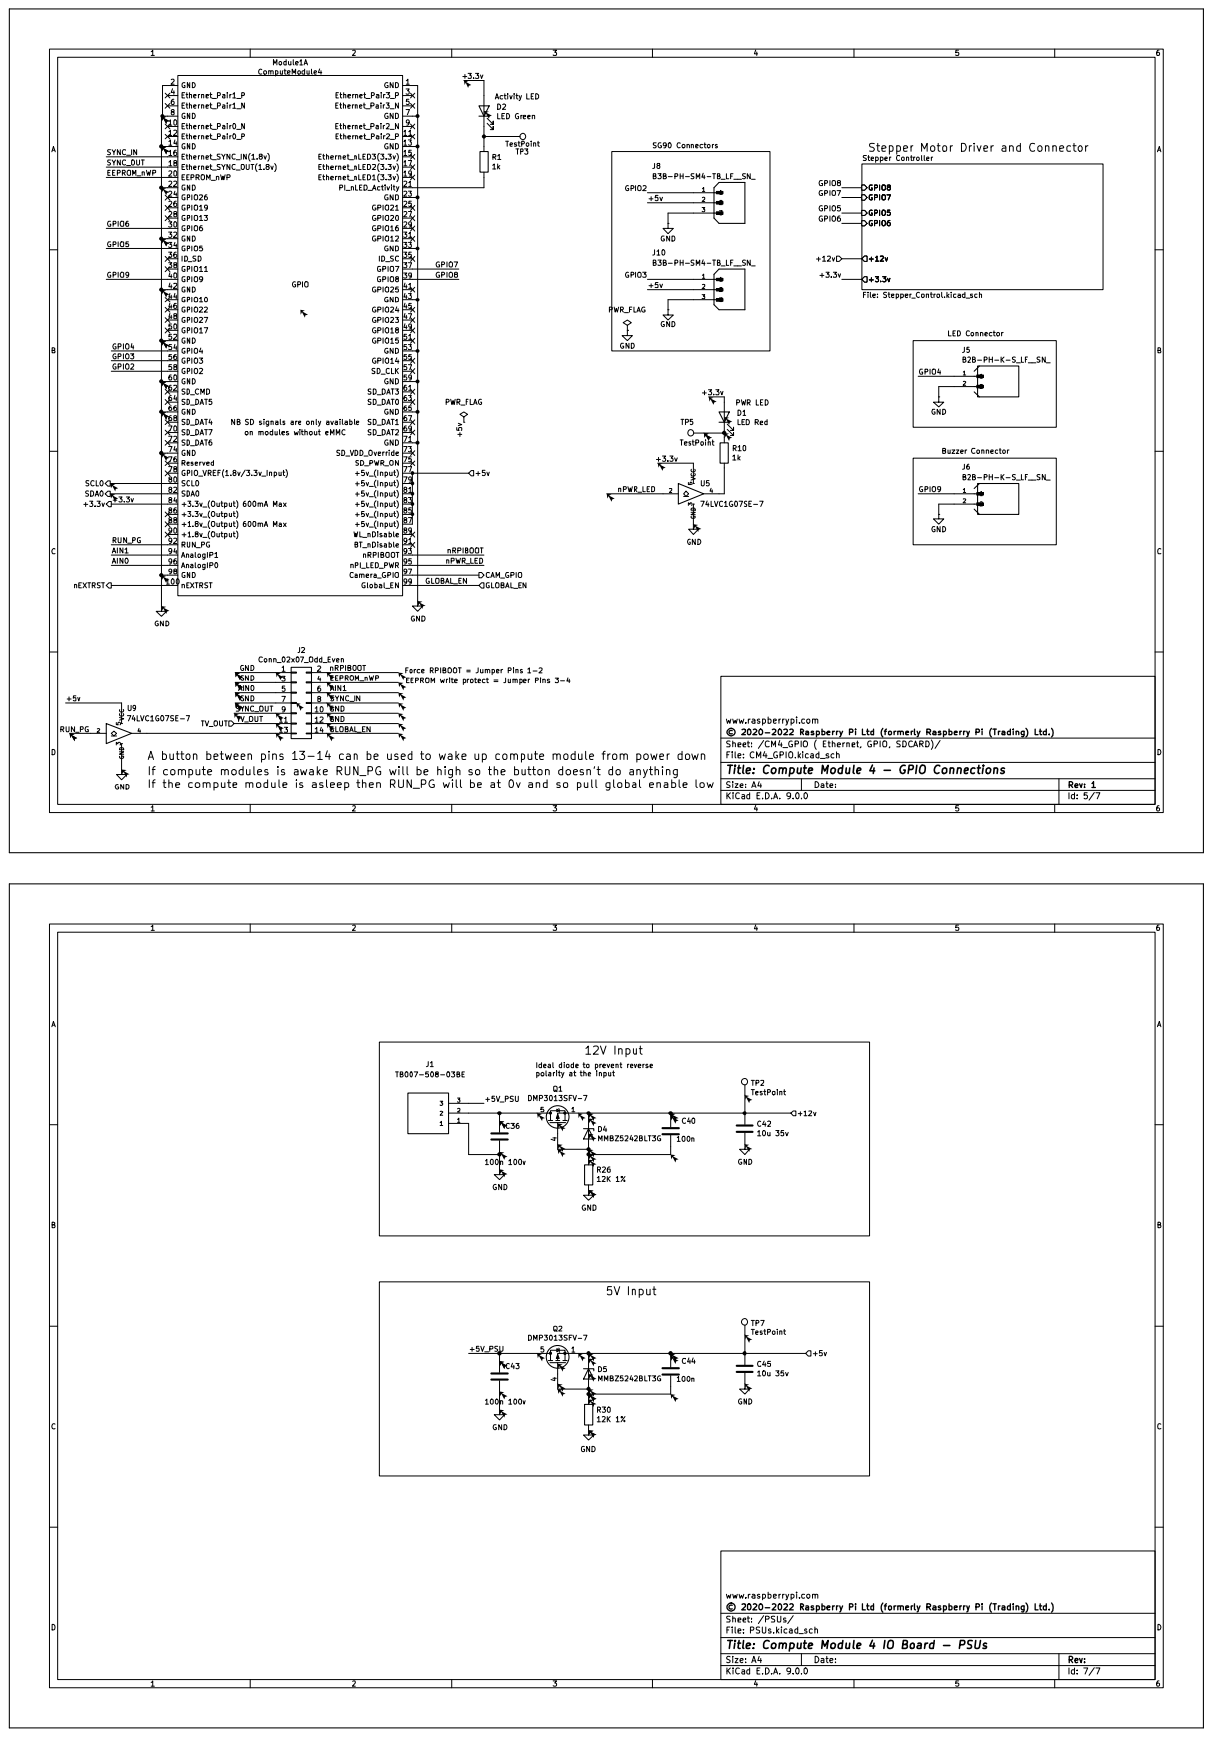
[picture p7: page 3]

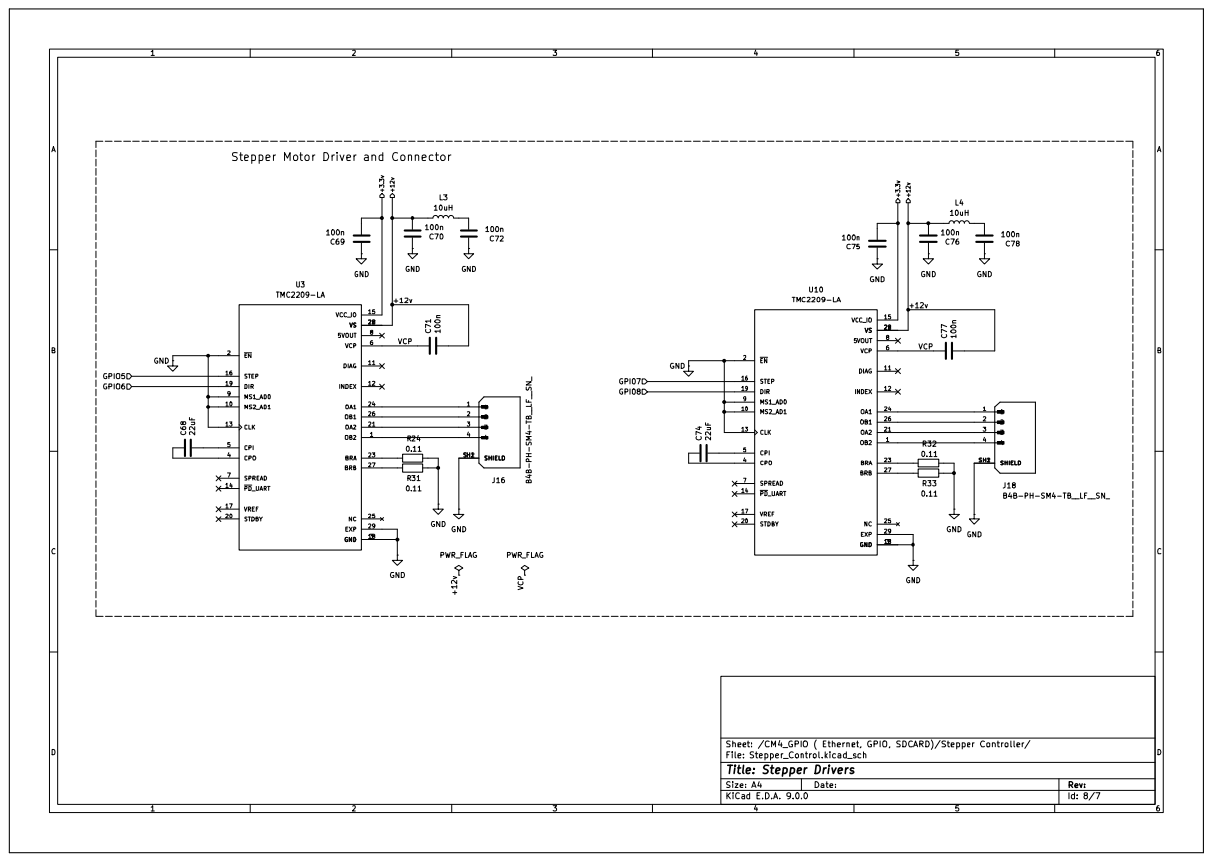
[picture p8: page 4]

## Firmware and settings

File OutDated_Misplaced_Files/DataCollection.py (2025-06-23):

'''
#ORIGIONAL DATA COLLECTION FILES, BELOW HAS ADJUSTMENTS FROM ASH, KEEP SCROLLING!!!

from picamera2 import Picamera2
from models.common import DetectMultiBackend
from utils.general import (non_max_suppression, scale_boxes, check_img_size, cv2)
from utils.torch_utils import select_device
from utils.augmentations import letterbox
from ultralytics.utils.plotting import Annotator, colors
from pillmatch import load_pills_from_db, find_match

import torch
import numpy as np
import time
import RPi.GPIO as GPIO

# Configs
weights_path = 'Multi3.pt'
imgsz = (640, 736)
conf_thres = 0.25
iou_thres = 0.45

# Initialize PiCamera2
picam2 = Picamera2()
config = picam2.create_video_configuration( main={"size": imgsz, "format" : "RGB888"} )
picam2.configure(config)
picam2.start()
time.sleep(2)

# Initialize Servo
GPIO_SER1 = 2
GPIO.setmode(GPIO.BCM)
GPIO.setup(2, GPIO.OUT)
GPIO.setup(18, GPIO.OUT)

pwm=GPIO.PWM(2, 50)

pwm.start(0)

def SetAngle(angle):
	duty = angle / 18 + 2
	GPIO.output(2, True)
	pwm.ChangeDutyCycle(duty)
	time.sleep(0.5)
	GPIO.output(2, False)
	pwm.ChangeDutyCycle(0)
    
def run_servo():
    #Servo Control
    SetAngle(60)
    time.sleep(0.75)

    SetAngle(0)

# Set device
device = select_device('')
model = DetectMultiBackend(weights_path, device=device)
stride, names, pt = model.stride, model.names, model.pt
imgsz = check_img_size(imgsz, s=stride)
model.warmup(imgsz=(1, 3, *imgsz))

def append_to_file(test_num, descriptors, matched_pills):
    with open("AshTest.txt", "a") as file:
        file.write(f"Test: {test_num}, Characteristics: {descriptors}, Pill: {matched_pills}\n")
        
def append_to_fail(test_num, descriptors, matched_pills):
    with open("AshTest.txt", "a") as file:
        file.write(f"Failed Test: {test_num}, Characteristics: {descriptors}, Pill: {matched_pills}\n")

#initialize database
pill_database = load_pills_from_db()

print(weights_path)
print(model.names)

print ("LED on")
GPIO.output(18, GPIO.HIGH)


test_num = 1
count = 0
# Detection loop
while True:
    frame = picam2.capture_array(wait=True)
    if frame.shape[2] == 4:
        frame = frame[:, :, :3]
    img = letterbox(frame, imgsz, stride=stride, auto=pt)[0]
    img = img.transpose((2, 0, 1))[::-1]  # HWC to CHW, BGR to RGB
    img = np.ascontiguousarray(img)

    im = torch.from_numpy(img).to(model.device)
    im = im.half() if model.fp16 else im.float()
    im /= 255
    im = im[None]  # add batch dim

    pred = model(im, augment=False, visualize=False)
    pred = non_max_suppression(pred, conf_thres, iou_thres)

    im0 = frame.copy()
    annotator = Annotator(im0, line_width=2, example=str(names))
    
    
    for det in pred:
        if len(det):
            count += 1
            print("pill detected")
            
            #BOX Drawing
            descriptors = set()
            det[:, :4] = scale_boxes(im.shape[2:], det[:, :4], im0.shape).round()
            for *xyxy, conf, cls in reversed(det):
                label = f'{names[int(cls)]} {conf:.2f}'
                annotator.box_label(xyxy, label, color=colors(int(cls), True))
                descriptor_label = names[int(cls)].lower()
                descriptors.add(descriptor_label)
                
            matched_pills = find_match(pill_database, descriptors, threshold=0.75)
            print(descriptors, matched_pills)
             
            if(count>=3):
                if matched_pills:  
                    for pill in matched_pills:
                        print(descriptors)
                        print(f"Pill dispense: {pill}")
                        print(test_num)
                        append_to_file(test_num, descriptors, matched_pills)
                        run_servo()
                        test_num += 1
                        count=0
                else: 
                    if (count>10):
                        append_to_fail(test_num, descriptors, matched_pills)
                        run_servo()
                        print (test_num)
                        count=0
                        test_num += 1
            

        time.sleep(0.5) #DELAY

    cv2.imshow("PiCam YOLOv5", annotator.result())
    if cv2.waitKey(1) & 0xFF == ord("q"):
        break

print ("LED off")
GPIO.output(18, GPIO.LOW)
cv2.destroyAllWindows()
pwm.stop()
GPIO.cleanup()
'''

from picamera2 import Picamera2
from models.common import DetectMultiBackend
from utils.general import (non_max_suppression, scale_boxes, check_img_size, cv2)
from utils.torch_utils import select_device
from utils.augmentations import letterbox
from ultralytics.utils.plotting import Annotator, colors
from pillmatch import load_pills_from_db, find_match, find_target
from datetime import datetime

import torch
import numpy as np
import time
import RPi.GPIO as GPIO

# Configs
weights_path = 'Multi4s.pt'
imgsz = (640, 736)
conf_thres = 0.25
iou_thres = 0.45
filename = "50Cordyceps2.txt"

# Initialize PiCamera2
picam2 = Picamera2()
config = picam2.create_video_configuration( main={"size": imgsz, "format" : "RGB888"} )
picam2.configure(config)
picam2.start()
time.sleep(2)

# Initialize Servo
GPIO_Servo_top = 14
GPIO.setmode(GPIO.BCM)
GPIO.setup(GPIO_Servo_top, GPIO.OUT)

p = GPIO.PWM(GPIO_Servo_top, 30)    #SG90 we use have a weird frequency (From testing this works best)
p.start(0)

#Create Instance of File or append to exisiting:
with open(filename, "a") as file:
        file.write(f"Test Batch: {datetime.now()}\n") #title of batch with date and time

def SetAngle(ServoIO, angle):
	duty = (angle / 36) + 5
	GPIO.output(ServoIO, True)      # Set pin high
	p.ChangeDutyCycle(duty)         #Place PWM signal over high pin
	time.sleep(1)                   # wait for motion
	GPIO.output(ServoIO, False)
	p.ChangeDutyCycle(0)
    
def run_servo(ServoIO):
    #Servo Control
    SetAngle(ServoIO, 60)
    time.sleep(0.75)
    SetAngle(ServoIO, 0)

# Set device
device = select_device('')
model = DetectMultiBackend(weights_path, device=device)
stride, names, pt = model.stride, model.names, model.pt
imgsz = check_img_size(imgsz, s=stride)
model.warmup(imgsz=(1, 3, *imgsz))

#Opens file to append success
def append_to_file(test_num, descriptors, matched_pills):
    with open(filename, "a") as file:
        file.write(f" Characteristics: {descriptors}, Pill: {matched_pills}\n")

#Opens file to append failure 
def append_to_fail(test_num, descriptors, matched_pills):
    with open(filename, "a") as file:
        file.write(f"Failed Test {test_num}, Characteristics: {descriptors}, Pill: {matched_pills}\n")

#initialize database
pill_database = load_pills_from_db()

print(weights_path)
print(model.names)

test_num = 1
count = 0
# Detection loop
while True:
    frame = picam2.capture_array(wait=True)
    if frame.shape[2] == 4:
        frame = frame[:, :, :3]
    img = letterbox(frame, imgsz, stride=stride, auto=pt)[0]
    img = img.transpose((2, 0, 1))[::-1]  # HWC to CHW, BGR to RGB
    img = np.ascontiguousarray(img)

    im = torch.from_numpy(img).to(model.device)
    im = im.half() if model.fp16 else im.float()
    im /= 255
    im = im[None]  # add batch dim

    pred = model(im, augment=False, visualize=False)
    pred = non_max_suppression(pred, conf_thres, iou_thres)

    im0 = frame.copy()
    annotator = Annotator(im0, line_width=2, example=str(names))
    
    
    for det in pred:
        if len(det):
            count += 1
            #print("pill detected")
            
            #BOX Drawing
            descriptors = set()
            det[:, :4] = scale_boxes(im.shape[2:], det[:, :4], im0.shape).round()
            for *xyxy, conf, cls in reversed(det):
                label = f'{names[int(cls)]} {conf:.2f}'
                annotator.box_label(xyxy, label, color=colors(int(cls), True))
                descriptor_label = names[int(cls)].lower()
                descriptors.add(descriptor_label)
                
            matched_pills = find_match(pill_database, descriptors, 0.75)
            #matched_pills = find_target(pill_database, descriptors, 'Cordyceps',0.75)
            print(descriptors, matched_pills)
             
            if(count>=3):
                if matched_pills:  
                    for pill in matched_pills:
                        print(descriptors)
                        print(f"Pill dispense: {pill}")
                        print(test_num)
                        append_to_file(test_num, descriptors, matched_pills)
                        run_servo(GPIO_Servo_top)
                        test_num += 1
                        count=0
                        
                        ''' Issue with find_match!! For something like the Cordyceps pill we get a detection when we have
                        beige and capsule, but we get a fail when we get beige, pill, and capsule. Idk what the issue is 
                        mainly cause of lack of understanding of the function. If you can try to iron this out that be rad.
                        find_target was my attempt at fixing it because in it real use case we would know the name of pill that
                        should be dispensed, thus we can just check its decriptor rather than loop through all the pills. Its 
                        not scaleable otherwise if we need to loop through 20000 pills in the db.'''
                        
                else: 
                    if (count>10):
                        append_to_fail(test_num, descriptors, matched_pills)
                        run_servo(GPIO_Servo_top)
                        print (test_num)
                        count=0
                        test_num += 1
            

        time.sleep(0.5) #DELAY
    
    cv2.imshow("PiCam YOLOv5", annotator.result())
    if cv2.waitKey(1) & 0xFF == ord("q"):
        break

#cv2.destroyAllWindows()
pwm.stop()
GPIO.cleanup()


            
            


            
            

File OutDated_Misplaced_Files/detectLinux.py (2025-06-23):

# Ultralytics 🚀 AGPL-3.0 License - https://ultralytics.com/license
"""
Run YOLOv5 detection inference on images, videos, directories, globs, YouTube, webcam, streams, etc.

Usage - sources:
    $ python detect.py --weights yolov5s.pt --source 0                               # webcam
                                                     img.jpg                         # image
                                                     vid.mp4                         # video
                                                     screen                          # screenshot
                                                     path/                           # directory
                                                     list.txt                        # list of images
                                                     list.streams                    # list of streams
                                                     'path/*.jpg'                    # glob
                                                     'https://youtu.be/LNwODJXcvt4'  # YouTube
                                                     'rtsp://example.com/media.mp4'  # RTSP, RTMP, HTTP stream
"""

# Standard library imports for file operations and system functions
import argparse           # For parsing command-line arguments
import csv                # For saving results in CSV format
import os                 # For operating system dependent functionality
import platform           # For getting information about the platform
import sys                # For system-specific parameters and functions
from pathlib import Path  # Object-oriented filesystem paths
import torch              # PyTorch import - the deep learning framework used by YOLOv5
from picamera2 import Picamera2
from ultralytics import YOLO
import cv2
import numpy as np

# Start Pi Camera
picam2 = Picamera2()
picam2.preview_configuration.main.size = (640, 480)
picam2.preview_configuration.main.format = "RGB888"
picam2.configure("video")
picam2.start()

# Setting up path to ensure imports work correctly
FILE = Path(__file__).resolve()         # Get the absolute path of the current file
ROOT = FILE.parents[0]                  # YOLOv5 root directory (parent directory of this file)
if str(ROOT) not in sys.path:
    sys.path.append(str(ROOT))          # Add ROOT to Python path if it's not already there
ROOT = Path(os.path.relpath(ROOT, Path.cwd()))  # Get the relative path from current working directory

# Import plotting utilities for visualization
from ultralytics.utils.plotting import Annotator, colors, save_one_box

# Import the core YOLOv5 components
from models.common import DetectMultiBackend  # For loading different model formats
from utils.dataloaders import IMG_FORMATS, VID_FORMATS, LoadImages, LoadScreenshots, LoadStreams  # Data loading utilities
from utils.general import (  # General utility functions
    LOGGER,             # Logger for printing status messages
    Profile,            # For timing code execution
    check_file,         # Verifies file existence
    check_img_size,     # Makes sure image size is valid for the model
    check_imshow,       # Checks if OpenCV's imshow will work
    check_requirements,  # Verifies required packages are installed
    colorstr,           # Colorizes terminal text
    cv2,                # OpenCV for image processing
    increment_path,     # Creates unique numbered run folders
    non_max_suppression,  # Removes overlapping bounding boxes
    print_args,         # Prints function arguments
    scale_boxes,        # Scales bounding boxes
    strip_optimizer,    # Removes training info from models
    xyxy2xywh,          # Converts box format from [x1,y1,x2,y2] to [x,y,width,height]
)
from utils.torch_utils import select_device, smart_inference_mode  # PyTorch specific utilities
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

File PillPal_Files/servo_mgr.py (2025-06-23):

import RPi.GPIO as GPIO
from time import sleep

class ServoManager:
    def __init__(self):
        # BCM pin numbers
        self.servo_pins = {
            1: 14,  # Door 1 → GPIO 2
            2: 3   # Door 2 → GPIO 3
        }

        GPIO.setmode(GPIO.BCM)
        GPIO.setup(14, GPIO.OUT)
        GPIO.setup(3, GPIO.OUT)
        
        self.pwm = [GPIO.PWM(14, 30), GPIO.PWM(3, 30)]
            
        for p in self.pwm: 
            p.start(0)

    def SetAngle(self, door, angle):
        pin = self.servo_pins[door]
        duty = angle / 36 + 5
        GPIO.output(pin, True)
        self.pwm[door-1].ChangeDutyCycle(duty)
        sleep(1)
        GPIO.output(pin, False)
        self.pwm[door-1].ChangeDutyCycle(0)

    def release_door(self, door):
        # Open and close the door using its servo
        print(f"release door {door}")
        if door in self.servo_pins:
            self.SetAngle(door, 60)  # Open
            sleep(1)
            self.SetAngle(door, 0)   # Close
        else:
            print(f"Invalid door ID: {door}")

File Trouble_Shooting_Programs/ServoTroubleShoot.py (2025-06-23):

import RPi.GPIO as GPIO
import time


Servo_pin = 14
GPIO.setmode(GPIO.BCM)
GPIO.setup(Servo_pin, GPIO.OUT)
p = GPIO.PWM(Servo_pin, 30)
p.start(0)


def SetAngle(angle):
	duty = (angle / 36) + 5
	GPIO.output(Servo_pin, True)    # Set pin high
	p.ChangeDutyCycle(duty)         #Place PWM signal over high pin
	time.sleep(1)                 # wait for motion
	GPIO.output(Servo_pin, False)
	p.ChangeDutyCycle(0)

try:
    while True:
        angle = int(input("Enter value -90 -> 90: "))
        if -90 <= angle <= 90:
            SetAngle(angle)
        else:
            print("Error, beyond limits")

finally:
    SetAngle(0)
    p.stop()
    GPIO.cleanup()
